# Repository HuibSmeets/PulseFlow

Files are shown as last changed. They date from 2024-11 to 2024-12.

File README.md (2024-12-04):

# PulseFlow
Control the speed of a cooling fan with your heart rate while riding/using your indoor trainer.

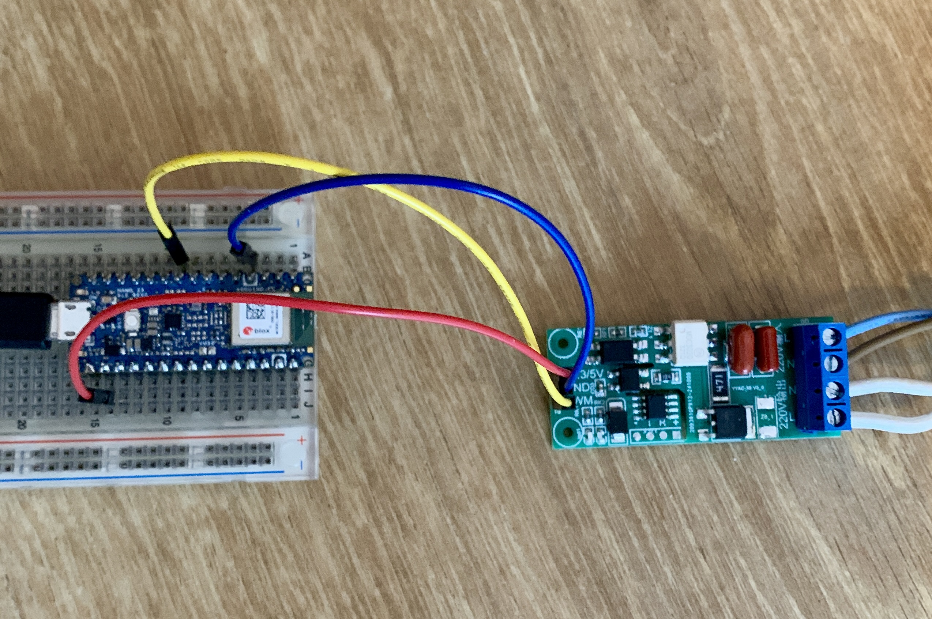
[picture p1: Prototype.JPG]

Image: Prototype, work in progress

## Description

**PulseFlow** is a small Arduino sketch that connects via BLE to a HR fitness sensor like those from Garmin, Wahoo and others. The fan is connected to a PWM controllable AC dimmer or a dimmer that exposes 2 pins: Output Zerocross detection, input triac trigger. These AC dimmers can be sourced from marketplaces like AliExpress.

## Warning
BE AWARE THAT YOU'LL BE WORKING WITH DEADLY LIVE VOLTAGES. TAKE APPROPRIATE SAFETY MEASURES WHEN CONNECTING PARTS AND WHILE USING THE DEVICE YOU CREATED. 

## Limitations

+ Your HR sensor must allow for multiple BLE connections as your trainer software/device will possiby have to connect to the sensor too using BLE (Garmin HR-Dual sensor supports multiple BLE connections)
+ Sensor pairing is hardcoded, see the sourcecode
+ Use a fan that has no electronic speed control of it's own.
+ The HR to fan speed mapping is hardcoded, see the sourcecode
+ In case of a PWM controlled dimmer:
  + The PWM signal is available on pin D6 (Arduino numbering)
  + Code to generate the PWM is Nano 33 BLE specific
+ In case of zero-cross/triac trigger dimmer:
  + Pin 2 (Arduino numbering) is used to detect the zero-crossing (interupt)
  + The triac trigger pulse is available on pin D6 (Arduino numbering)
  + The delay implementation between the zero-crossing and the triactrigger is Nano 33 BLE specific
+ As the NANO is a 3.3V device the AC dimmer you use must be 3.3v tolerable/compatible (or add levelshifting)
+ Installing the various parts in a metal of shielded housing can influense the BLE RF signal

## Possible enhancements

+ Do away with hardcoded pairing
+ Create an UI (e.g. a 2-Line display and rotary encoder) for pairing, map settings. 
+ Alternate fan speed mapping methods (speed, power,...).

## Change Log

### in development (main)
+ code cleanup
+ added battery level check
+ delayed switch off

### v1.1.0
+ added code for 2nd type of dimmer

### v1.0.0
+ Initial release

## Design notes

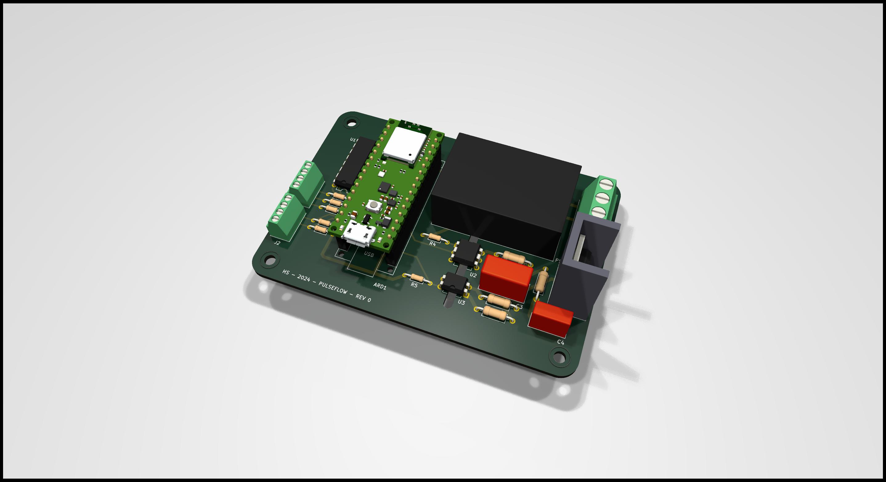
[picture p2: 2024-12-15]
pcb/PulseFlow - PCB - 1.jpg

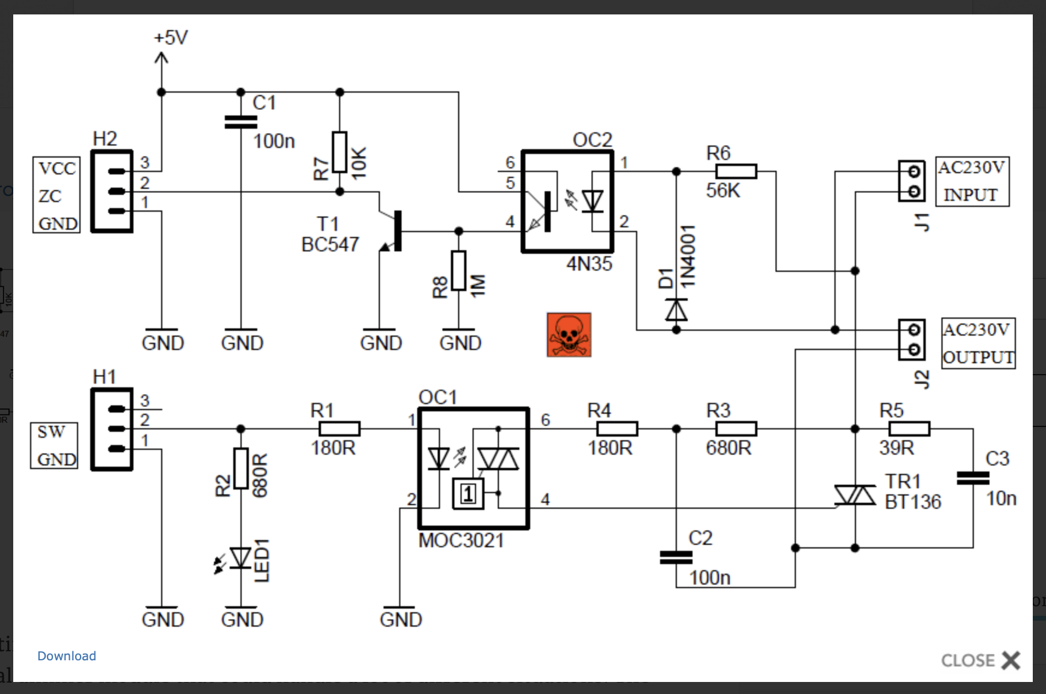
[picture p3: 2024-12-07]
pcb/Schema.png

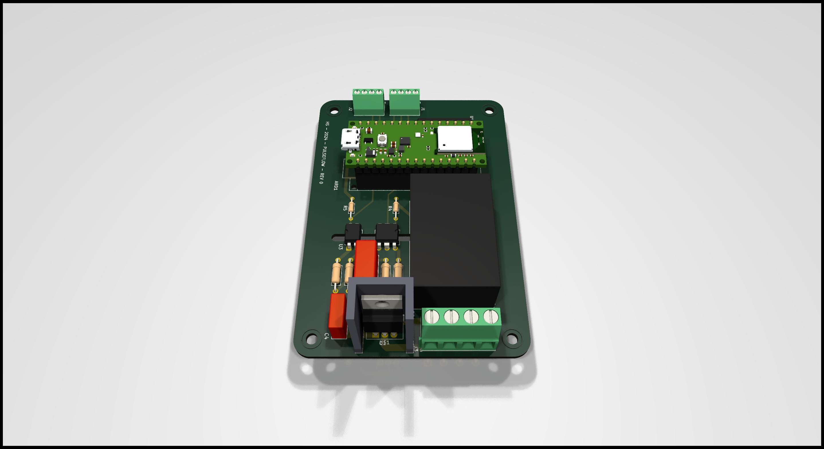
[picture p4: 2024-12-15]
pcb/PulseFlow - PCB - 2.jpg

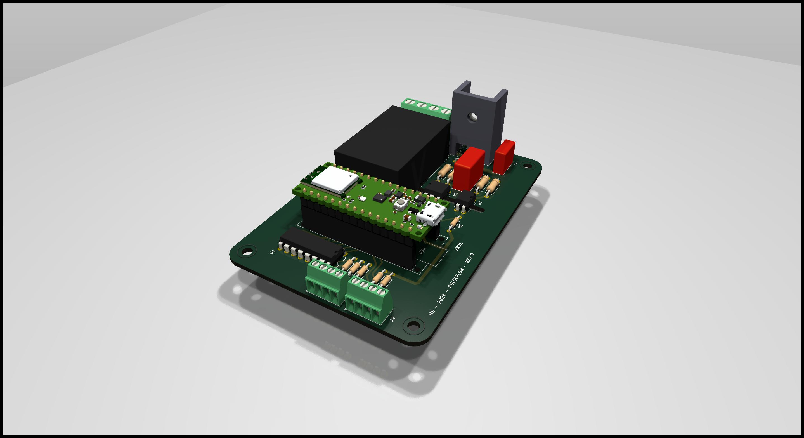
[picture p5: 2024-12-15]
pcb/PulseFlow - PCB - 3.jpg

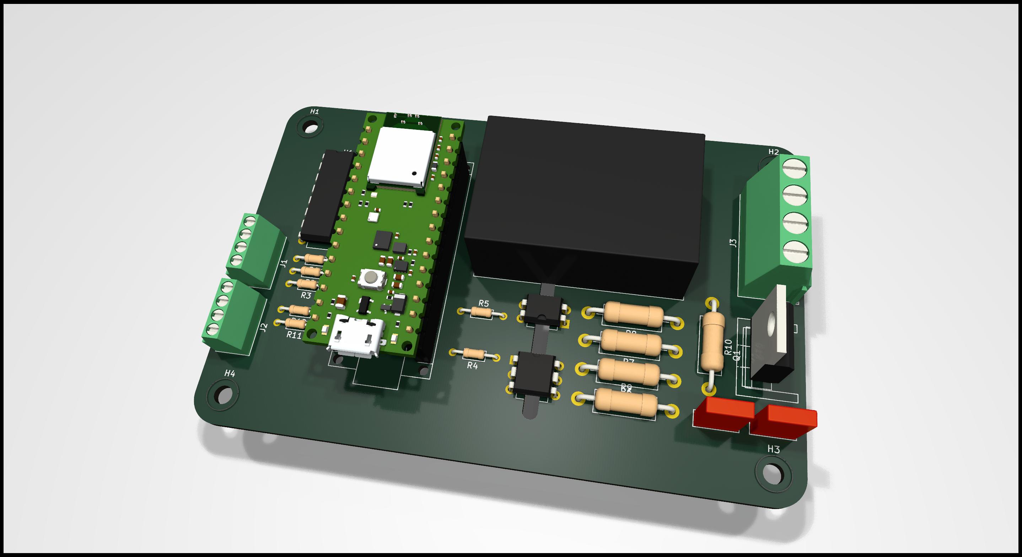
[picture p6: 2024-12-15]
pcb/PulseFlow - PCB.jpg

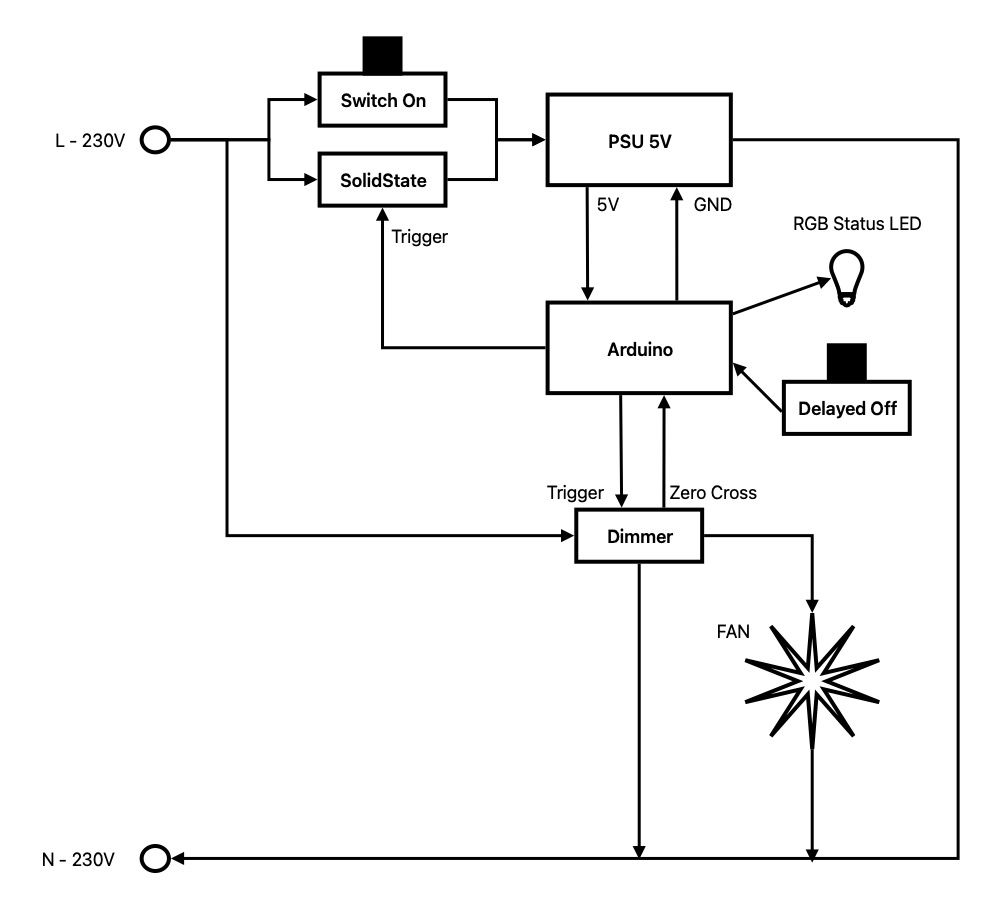
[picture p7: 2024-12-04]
various/Principled Connection Diagram.jpg

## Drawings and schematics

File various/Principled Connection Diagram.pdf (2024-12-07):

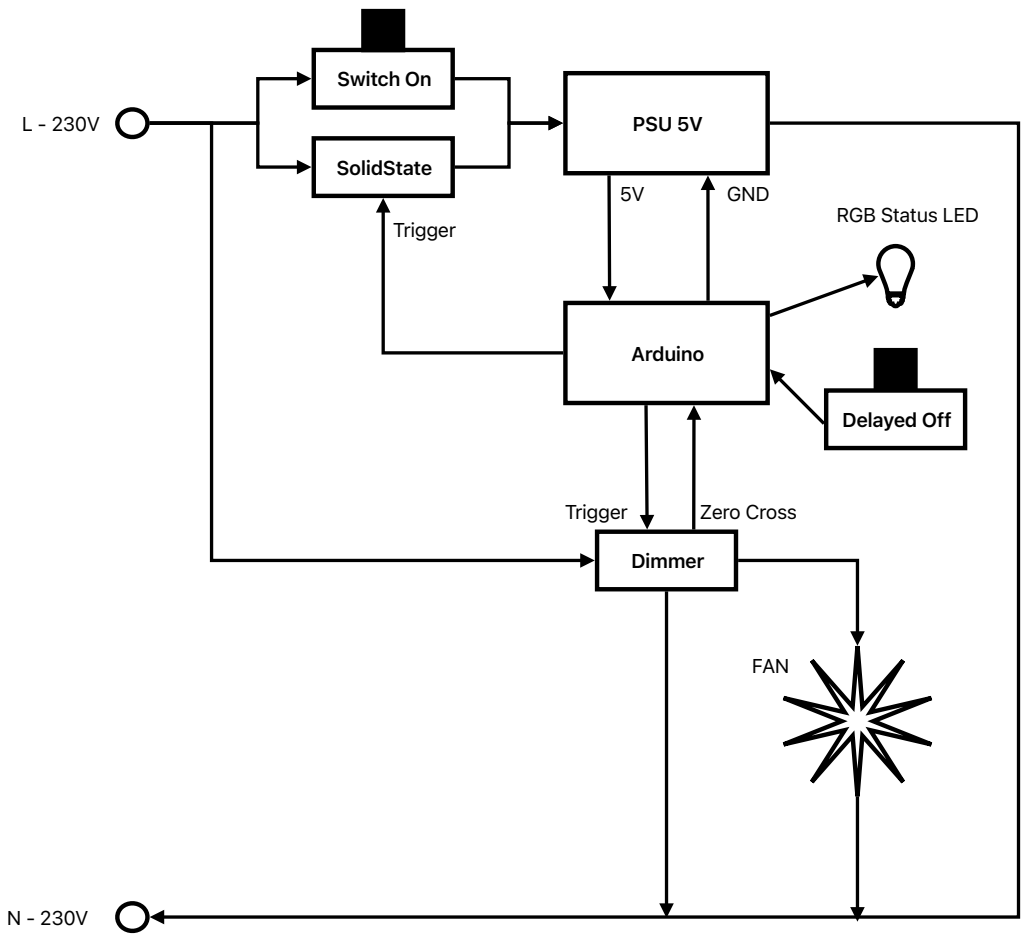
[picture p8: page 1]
SolidState; Switch On; Arduino; PSU 5V; Dimmer; Trigger; Zero Cross; GND; Delayed Off; FAN

RGB Status LED

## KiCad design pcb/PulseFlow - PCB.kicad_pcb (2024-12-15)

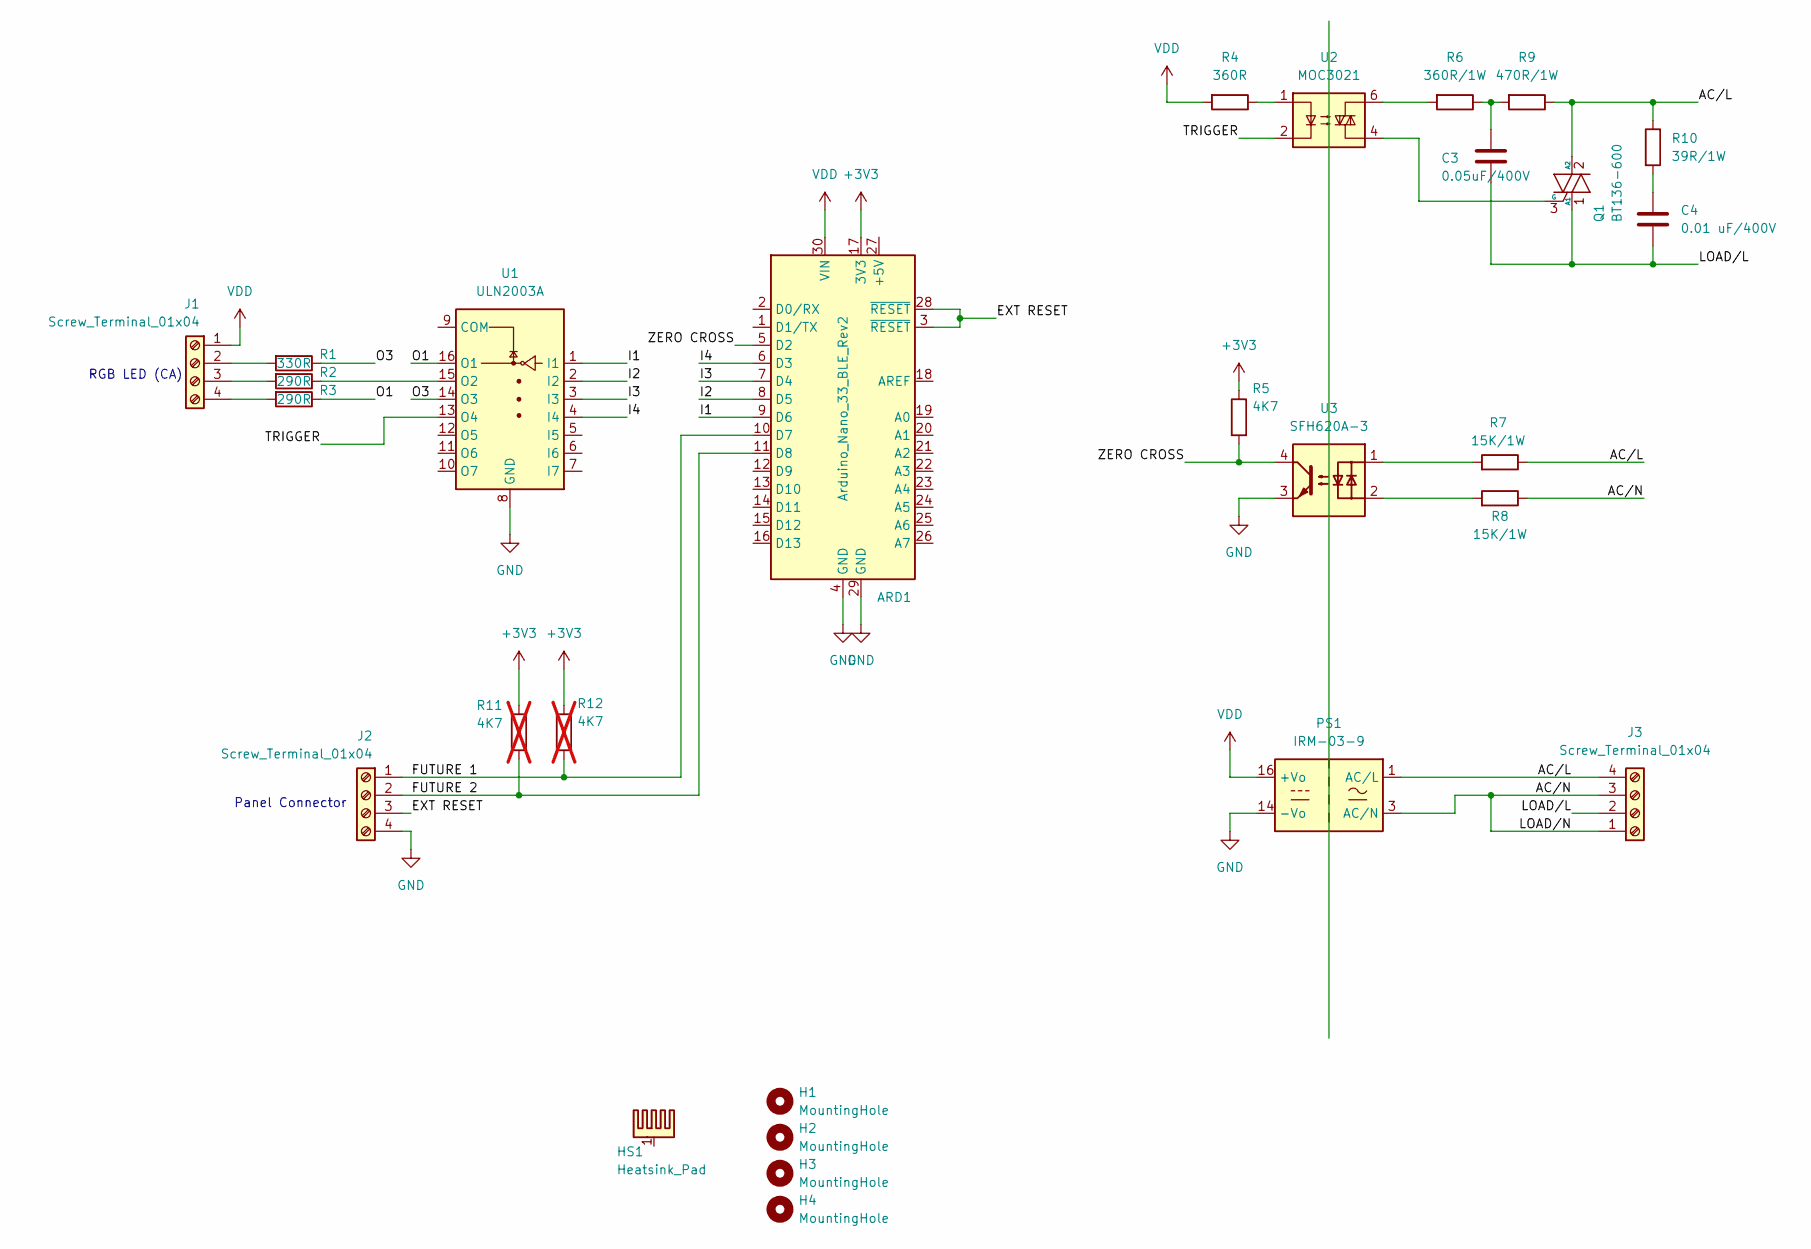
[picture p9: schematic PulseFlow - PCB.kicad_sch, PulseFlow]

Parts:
ARD1: Arduino_Nano_33_BLE_Rev2; Arduino_Nano_WithMountingHoles
C3: 0.05uF/400V; C_Rect_L13.0mm_W6.0mm_P10.00mm_FKS3_FKP3_MKS4
C4: 0.01 uF/400V; C_Rect_L10.0mm_W4.0mm_P7.50mm_FKS3_FKP3
H1, H2, H3, H4: MountingHole; MountingHole_3.2mm_M3_ISO14580
HS1: Heatsink_Pad; Heatsink_Fischer_SK-431-1x25mm
J1, J2: Screw_Terminal_01x04; TerminalBlock_Phoenix_MPT-0,5-4-2.54_1x04_P2.54mm_Horizontal
J3: Screw_Terminal_01x04; TerminalBlock_Phoenix_MKDS-1,5-4-5.08_1x04_P5.08mm_Horizont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
PS1: IRM-03-9; Converter_ACDC_MeanWell_IRM-03-xx_THT
Q1: BT136-600; TO-220-3_Vertical
R1: 330R; R_Axial_DIN0207_L6.3mm_D2.5mm_P10.16mm_Horizontal
R2, R3: 290R; R_Axial_DIN0207_L6.3mm_D2.5mm_P10.16mm_Horizontal
R4: 360R; R_Axial_DIN0207_L6.3mm_D2.5mm_P10.16mm_Horizontal
R5: 4K7; R_Axial_DIN0207_L6.3mm_D2.5mm_P10.16mm_Horizontal
R6: 360R/1W; R_Axial_DIN0207_L6.3mm_D2.5mm_P10.16mm_Horizontal
R7, R8: 15K/1W; R_Axial_DIN0207_L6.3mm_D2.5mm_P10.16mm_Horizontal
R9: 470R/1W; R_Axial_DIN0207_L6.3mm_D2.5mm_P10.16mm_Horizontal
R10: 39R/1W; R_Axial_DIN0207_L6.3mm_D2.5mm_P10.16mm_Horizontal
R11, R12: 4K7; R_Axial_DIN0207_L6.3mm_D2.5mm_P10.16mm_Horizontal; not fitted
U1: ULN2003A; DIP-16_W7.62mm
U2: MOC3021; DIP-6_W7.62mm
U3: SFH620A-3; DIP-4_W7.62mm

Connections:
+3V3: ARD1.17 (3V3), R5.1, R11.1, R12.1
/AC/L: J3.4, PS1.1 (AC/L), Q1.2 (A2), R7.1, R9.1, R10.1
/AC/N: J3.1, J3.3, PS1.3 (AC/N), R8.1
/EXT RESET: ARD1.3 (~RESET), ARD1.28 (~RESET), J2.3
/FUTURE 1: ARD1.10 (D7), J2.1, R12.2
/FUTURE 2: ARD1.11 (D8), J2.2, R11.2
/I1: ARD1.9 (D6), U1.1 (I1)
/I2: ARD1.8 (D5), U1.2 (I2)
/I3: ARD1.7 (D4), U1.3 (I3)
/I4: ARD1.6 (D3), U1.4 (I4)
/LOAD/L: C3.2, C4.2, J3.2, Q1.1 (A1)
/O1: R3.1, U1.16 (O1)
/O3: R1.1, U1.14 (O3)
/TRIGGER: U1.13 (O4), U2.2
/ZERO CROSS: ARD1.5 (D2), R5.2, U3.4
GND: ARD1.4 (GND), ARD1.29 (GND), J2.4, PS1.14 (-Vo), U1.8 (GND), U3.3
unnamed: C3.1, R6.1, R9.2
unnamed: C4.1, R10.2
unnamed: J1.2, R1.2
unnamed: J1.3, R2.2
unnamed: J1.4, R3.2
unnamed: Q1.3 (G), U2.4
unnamed: R4.1, U2.1
unnamed: R6.2, U2.6
unnamed: R7.2, U3.1
unnamed: R8.2, U3.2
unnamed: R2.1, U1.15 (O2)
VDD: ARD1.30 (VIN), J1.1, PS1.16 (+Vo), R4.2

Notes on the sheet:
Panel Connector
RGB LED (CA)

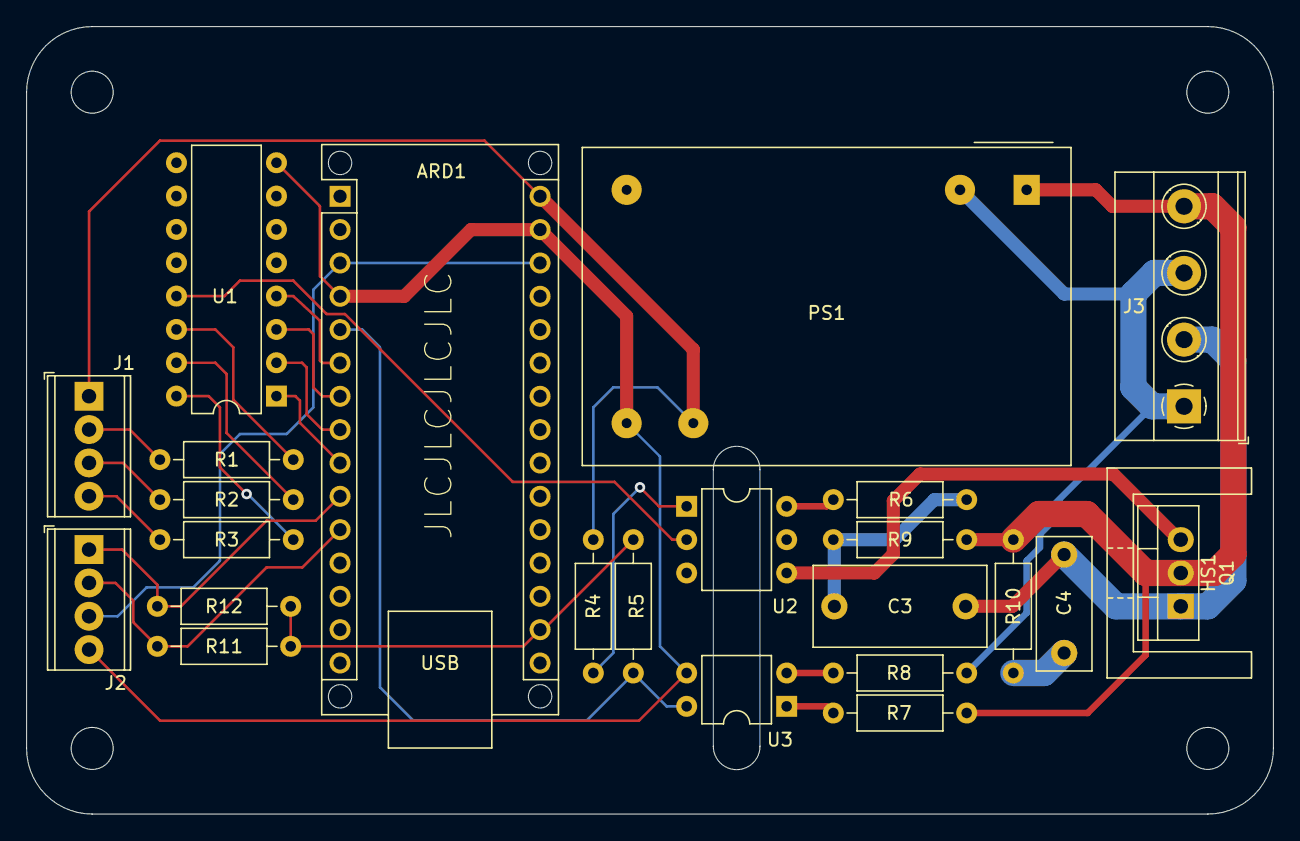
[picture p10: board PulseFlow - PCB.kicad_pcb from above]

Board: 2 copper layers, 95.0 x 60.0 mm, 28 parts (0 on the bottom side), 28 nets.

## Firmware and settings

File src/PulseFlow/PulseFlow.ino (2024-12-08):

/*
 * This file is part of PulseFlow.
 *
 * Copyright (C) 2024 Huib Smeets (pulseflow[at]huibsmeets[dot]com)
 *
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
 * You should have received a copy of the GNU General Public License
 * along with [Project Name]. If not, see <https://www.gnu.org/licenses/>.
 */

#include <ArduinoBLE.h>
#include <mbed.h>

// ********************************************************************************************
// START OF CONFIG SECTION
// ********************************************************************************************

// There is no sensor pairing functionality implemented under the assumption that there is only 1
// HR sensor active while using the indoor trainer in private spaces.
// However some trainers have a HR bridge function.
// To prevent connecting to the trainer HR service the name of the sensor to use is hardcoded (and unique)
// Your HR sensor name can be obtained by using the NRF Connect app or via your trainer software (Zwift, Rouvy, etc)

#define SENSORNAME "HRM-Dual:560827"

// set the battery low treshold percentage, below this threshold a slow blinking green LED signals a low battery charge
// Garmin sensors cannot be recharged, have to replace the battery, but use a fairly low treshold like 10 to 15
// Wahoo sensors are rechargeble, set a higher treshold (20 to 25) as these drain faster

#define SENSORBATLOW 15

// The number of heartrate samples to smooth single readings.
// The sensor is read once per second and the fanspeed is adjusted once per HRSAMPLES seconds.
// The fan has some inertia of it's own, more frequent adjustments have little use

#define HRSAMPLES 5

// HR is mapped to the fan speed with the Arduino map() function
// A midpoint value is available to alter the steepness of the linear map at some point
// HR values in bpm, fanspeed in percentage 0-100%
// Adjust these 6 values to your own heart rates (and non-linearities of the fan).

#define MINHR 100
#define MIDHR 140
#define MAXHR 160
#define MINFAN 30
#define MIDFAN 60
#define MAXFAN 100


// Set the type of AC dimmer that is beeing used:
//    PWM: Dimmer controlled by PWM
//    ZCD: Dimmer that signals Zero-Crossing, sketch calculates the trigger Delay

// #define PWM
#define ZCD

// ******************************************************************************************
// END OF CONFIG SECTION
// ******************************************************************************************

unsigned long currentMillis;

// Used for non-blocking(delay) blue LED blinking to signal peripheral searching

unsigned long previousMillisLED = 0;
bool ledState = false;

#ifdef PWM

// To regulate the speed of the fan a PWM controlled AC dimmer is used, can be sourced from AliExpress.
// Tests showed that this AC dimmer works better at a lower PWM frequency than the standard Arduino PWM frequency
// Instead of analogWrite() a MBED OS PWM function is used to generate a 250Hz PWM, therefore that piece of code is
// Nano 33 BLE Rev 2 specific

mbed::PwmOut* pwmOnPin = new mbed::PwmOut(digitalPinToPinName(D6));

#endif

#ifdef ZCD

// To regulate the speed of the fan an AC dimmer with Zero Crossing detection is used, can be sourced from AliExpress.
// For delay timing of the triac trigger Nano 33 BLE Rev 2 specific code is used.

#include <nrf_timer.h>

// Pin definitions
const uint8_t interruptPin = 2;  // Zero cross detection pin to trigger an interrupt
const uint8_t triacPin = 6;      // Triac gate trigger pin

// Constants
const uint32_t pulseWidthUs = 50;         // Pulse width in microseconds for the triac gate to start conducting
const uint32_t halfSineDuration = 10000;  // half-sine wave duration in microseconds 50Hz: 10000us, 60Hz: 8333us

// Global parameter storing the current dimming value (leading edge trimming)
volatile uint8_t dimmingPercentage = 0;

// Interrupt handler for the Zero Crossing

void handleZC() {

  NVIC_DisableIRQ(TIMER3_IRQn);

  // in case dimming at the lowest and highest range: CPU cycles consume time which causes timing mis-align with the actual
  // zero crossing/sine therefore at the lowest and highest values the dimmer is just shutoff or switched on permanentely.
  // Timer is only used in the in-between values. Timer3: 1MHz --> Delay thus calculated in microseconds.
  // you can experiment with other values then 5 and 95 closer to 0 and 100.

  switch (dimmingPercentage) {
    case 0 ... 5:
      {
        digitalWrite(triacPin, LOW);
        break;
      }
    case 95 ... 100:
      {
        digitalWrite(triacPin, HIGH);
        //        delayMicroseconds(pulseWidthUs);
        //        digitalWrite(triacPin, LOW);
        break;
      }
    default:
      {
        NRF_TIMER3->TASKS_CLEAR = 1;
        NRF_TIMER3->CC[0] = halfSineDuration - (uint32_t)dimmingPercentage * halfSineDuration / 100.0;
        NRF_TIMER3->TASKS_START = 1;
        NVIC_EnableIRQ(TIMER3_IRQn);
      }
  }
}

// Timer3 Event Handler --> delay ended, trigger the triac

extern "C" void TIMER3_IRQHandler_v(void) {
  NVIC_DisableIRQ(TIMER3_IRQn);

  if (NRF_TIMER3->EVENTS_COMPARE[0] == 1) {

    NRF_TIMER3->EVENTS_COMPARE[0] = 0;  // Clear the compare event

    digitalWrite(triacPin, HIGH);  // Create a puls to trigger the triac
    delayMicroseconds(pulseWidthUs);
    digitalWrite(triacPin, LOW);

    NRF_TIMER3->TASKS_STOP = 1;  // Stop the timer
  }
  NVIC_EnableIRQ(TIMER3_IRQn);
}

#endif

void setupFanController() {

#ifdef PWM

  //Set the PWM frequency to 250Hz (4ms), set duty-cycle to 0 -> Fan is off

  pwmOnPin->period_ms(4);
  pwmOnPin->write(0.0f);

#endif

#ifdef ZCD

  // configure the pin used to trigger the triac

  pinMode(triacPin, OUTPUT);
  digitalWrite(triacPin, LOW);

  // setup Timer3: 32b, timermode, 1Mhz, automatic clear

  NRF_TIMER3->BITMODE = TIMER_BITMODE_BITMODE_32Bit << TIMER_BITMODE_BITMODE_Pos;
  NRF_TIMER3->MODE = TIMER_MODE_MODE_Timer << TIMER_MODE_MODE_Pos;
  NRF_TIMER3->PRESCALER = 4UL << TIMER_PRESCALER_PRESCALER_Pos;
  NRF_TIMER3->INTENSET = TIMER_INTENSET_COMPARE0_Enabled << TIMER_INTENSET_COMPARE0_Pos;
  NRF_TIMER3->SHORTS = TIMER_SHORTS_COMPARE0_CLEAR_Enabled << TIMER_SHORTS_COMPARE0_CLEAR_Pos;

  // configure the pin used to generate an interupt on a rising edge

  pinMode(digitalPinToInterrupt(interruptPin), INPUT);
  attachInterrupt(digitalPinToInterrupt(interruptPin), handleZC, RISING);

#endif
}

void adjustFanSpeed(int percentage) {

  // Range check

  if (percentage < 0) percentage = 0;
  if (percentage > 100) percentage = 100;

#ifdef PWM

  pwmOnPin->write(percentage / 100.0f);  //division must result in a float

#endif

#ifdef ZCD

  dimmingPercentage = percentage;

#endif
}

// Workaround for an ArduinoBLE issue(s), see below.
unsigned long previousMillisBLE = millis();

void setup() {

  // do needed setups for the attached controller/dimmer, start the fan

  setupFanController();
  adjustFanSpeed(MINFAN);


  //Set the builtin RGB LED's ports to Output, but this turns the LED's on too!
  //as the On/Off logic is inverted due to the NANO 33 BLE hardware design.
  //Switch the LED of by setting the port to HIGH
  //FIXME: explicit OUTPUT setting needed?

  pinMode(LEDR, OUTPUT);
  digitalWrite(LEDR, HIGH);
  pinMode(LEDB, OUTPUT);
  digitalWrite(LEDB, HIGH);
  pinMode(LEDG, OUTPUT);
  digitalWrite(LEDG, HIGH);

  // Initialize the BLE hardware/environment/library,
  // if fatal error turn on the RED LED and keep trying

  while (!BLE.begin()) {
    digitalWrite(LEDR, LOW);
    delay(1000);
  };
  digitalWrite(LEDR, HIGH);

  // start scanning for a peripheral advertising the Heart Rate Measurement Service (GATT: UID=180D)

  previousMillisBLE = 0;
  BLE.scanForUuid("180D");
}

void loop() {

  // Check if a peripheral is found and its name matches the sensorname, if not: continue scanning

  BLEDevice peripheral = BLE.available();
  if (peripheral && peripheral.localName() == SENSORNAME) {

    // End scanning to save on resouces

    BLE.stopScan();

    // The sensor has been found, turn on the blue LED

    digitalWrite(LEDB, LOW);

    // The "main business" loop of reading sensor values and adjusting the fan speed
    // until the sensor is no longer connected

    HR2FAN(peripheral);

    // The sensor is not connected anymore, start searching again

    previousMillisBLE = millis();
    BLE.scanForUuid("180D");

  } else {

    // As long as no sensor is found blink the blue led.
    // No delay() is used as it interferes with the BLE.scan() function.

    currentMillis = millis();
    if (currentMillis - previousMillisLED >= 500) {
      previousMillisLED = currentMillis;
      ledState = !ledState;
      digitalWrite(LEDB, ledState ? HIGH : LOW);
    }

    // There seems to be an issue with the BLE.scan function and/or Nano 33 BLE Rev2.
    // After about 5 to 10 minutes of scanning for peripherals the BLE.scan function does not work anymore.
    // The workaround is a crowbar to reboot the arduino every 2 minutes

    if (currentMillis - previousMillisBLE >= 180000) {
      NVIC_SystemReset();
    }
  }
}

void HR2FAN(BLEDevice peripheral) {

  byte BatteryLevel;
  bool BatteryGood = true;
  byte HRMcharvalue[2];
  uint8_t HRsampleValue[HRSAMPLES];
  int HRsampleCount;
  int FanSpeedPercentage;
  int HRavg;

  // Connect to the found peripheral, if not able to connect: exit and start searching for a periphiral again.

  if (!peripheral.connect()) {
    return;
  }

  // Check for attributes of the periphiral, if none found: disconnect, return to search again

  if (!peripheral.discoverAttributes()) {
    peripheral.disconnect();
    return;
  }

  // Retrieve the battery level, if 2A19 not present, assume battery charge level is always okay.

  BatteryGood = true;
  BLECharacteristic BATCharacteristic = peripheral.characteristic("2A19");
  if (BATCharacteristic) {
    BATCharacteristic.readValue(&BatteryLevel, 1);
    if ((uint8_t)BatteryLevel <= SENSORBATLOW) BatteryGood = false;
  }

  // Retrieve the heart rate characteristic (2A37), if not available: disconnect, return to search again

  BLECharacteristic HRCharacteristic = peripheral.characteristic("2A37");
  if (!HRCharacteristic) {
    peripheral.disconnect();
    return;
  }

  // The heart rate characteristic is a 'Notify' and must be subscribed to, to get values
  // If not able to subscribe: disconnect, return to search again

  if (!HRCharacteristic.subscribe()) {
    peripheral.disconnect();
    return;
  }

  // A connection is established, turn the blue LED off and green LED on

  digitalWrite(LEDG, LOW);
  digitalWrite(LEDB, HIGH);

  // Inititalize the array with HR samples to zero

  for (int i = 0; i < HRSAMPLES; i++) HRsampleValue[i] = 0;
  HRsampleCount = 0;


  // As long a the sensor is connected: read the HR from the sensor

  while (peripheral.connected()) {

    // The characterisc 2A37 is of type Notify, check if a notification was send by the sensor

    if (HRCharacteristic.valueUpdated()) {

      // Sensor attribute values are send as a variable length byte array
      // In case of the hearth rate it can be 2 to 512 bytes long
      // The first byte contains 8 flags (5 defined, 3 for future use, see GATT specs)
      // the first bit in the flag byte defines if the heart rate is send in 1 or 2 bytes, 8 or 16 interger.
      // This Arduino sketch takes a short-cut: it ignores this all as the Garmin sensor only uses 1 byte to send the HR value

      if (HRCharacteristic.readValue(HRMcharvalue, 2)) {
        HRsampleValue[HRsampleCount] = HRMcharvalue[1];  //retrieve the HR from the 2nd byte
        HRsampleCount++;
      }
      // When the set number of HR samples have been read: calculate the average, map the HR to the duty cycle, adjust the fan speed

      if (HRsampleCount >= HRSAMPLES) {

        // Average HR calculation

        HRavg = 0;
        for (int i = 0; i < HRSAMPLES; i++) HRavg += HRsampleValue[i];
        HRavg = HRavg / HRSAMPLES;

        // the map function returns out of range values when the input is also out of the set range
        // if the HR is outside the map range, set the duty cycle to its minimum or maximum

        if (HRavg < MINHR) {
          FanSpeedPercentage = MINFAN;
        }
        if (HRavg > MAXHR) {
          FanSpeedPercentage = MAXFAN;
        }

        // Map the HR to a dutycycle, low to mid and mid to high ranges

        if (HRavg >= MINHR && HRavg <= MIDHR) {
          FanSpeedPercentage = map(HRavg, MINHR, MIDHR, MINFAN, MIDFAN);
        }
        if (HRavg > MIDHR && HRavg <= MAXHR) {
          FanSpeedPercentage = map(HRavg, MIDHR, MAXHR, MIDFAN, MAXFAN);
        }

        // adjust the speed of the fan

        adjustFanSpeed(FanSpeedPercentage);

        // clear the array with HR samples

        HRsampleCount = 0;
        for (int i = 0; i < HRSAMPLES; i++) HRsampleValue[i] = 0;
      }

      // If the sensor battery charge is low then 'slowly' blink the green LED

      if (!BatteryGood) {
        ledState = !ledState;
        digitalWrite(LEDG, ledState ? HIGH : LOW);
      }
      delay(1000);
    }
  }
  // connection lost, set fan to a defined speed, switch off the green LED

  adjustFanSpeed(MINFAN);

  digitalWrite(LEDG, HIGH);
}

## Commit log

2024-11-21 Added remark about type of fan to be used.
2024-11-21 Various corrections in the comments
    [PulseFlow.ino]
2024-11-25 Possible enhancement added: Battery check
2024-11-26 Alternative Dimmer
    Code added to use a different dimmer that only exposes 2 pins: one to detect the sinus zero-crossing and a pin to trigger the triac.
2024-11-30 Reset BLE tweak
    BLE.start() failed the other day in the reset every 5 minutes while scanning loop, changed to code to retry indefinitely.
    [PulseFlow.ino]
2024-12-01 Changed BLE restart to a system reboot
    [PulseFlow.ino]
2024-12-01 Some code cleanup + battery level check added
2024-12-08 Fix the bug fix
    [PulseFlow.ino]

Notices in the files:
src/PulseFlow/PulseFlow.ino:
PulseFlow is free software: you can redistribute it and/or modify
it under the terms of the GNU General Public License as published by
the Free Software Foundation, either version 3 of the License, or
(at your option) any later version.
